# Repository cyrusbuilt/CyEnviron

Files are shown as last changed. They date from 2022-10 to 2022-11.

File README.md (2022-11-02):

# CyEnviron

Environmental Monitoring System (ESP-8266 based)



CyEnviron is an indoor environmental monitoring system designed to be integrated with home-automation systems. This repository contains the firmware, schematics, PCB design files, and OpenHAB3 integration.

## Theory of Operation

Once every 5 seconds (by default), CyEnviron will take the following measurements and then publish a status payload (in JSON format) to it's status topic in [MQTT](https://mqtt.org/):

- Temperature
- Humdity
- Barometric Pressure
- Altitude above sealevel
- Gas Resistance
- Ambient light level
- Indoor Air Quality (IAQ)
- Air Quality Index (AQI)
- CO2 Equivalent
- Breath Volatile Organic Compounds (Breath VOC)
- Dew Point

Ambient light level is sampled using an [LDR/CDS Photocell](https://www.electronics-notes.com/articles/electronic_components/resistors/light-dependent-resistor-ldr.php). All other measurements are sampled using an [Adafruit BME688/BME680](https://www.adafruit.com/product/5046). At present, the more advanced features such as integrated AI (BME688), IAQ (Indoor Air Quality), and VOC (Volatile Organic Compound) sampling are not yet supported (but will be in a future firmware release). Specifically, this project was designed to use the BME688 module, but the BME680 *can* be used instead (especially since the more advanced features of the 688 are not yet implemented).  In a future release, I also intend to support alarm thresholds for certain values. Once the threshold value(s) are exceeded an audible and visible alarm will trigger and also be published as part of the status payload.

## IMPORTANT NOTE

It is very important that you *DO NOT* touch the BME680/BME688 sensor during assembly so as not to contaminate the sensor. I'm not currently aware of any way to decontimnate it. Once contaminated, you will no longer get accurate readings.

## Project Structure

This is a [PlatformIO](https://platformio.org/) project, so please refer to the PlatformIO documentation for building,

```
|-- .github          # Continuous Integration stuff
|-- data             # Configuration data. Anything in here gets flashed when uploading a filesystem image.
|-- include          # Contains C++ header files for the firmware.
|-- openhab          # Contains OpenHAB3 integration files.
|-- schematics       # Contains schematics (EasyEDA and PDF), PCB design (EasyEDA and PDF), BOM, and gerbers.
|-- src              # Contains C++ source files for the firmware.
|-- LICENSE          # MIT open source license.
|-- platformio.ini   # PlatformIO project configuration file.
|-- README.md        # This file.
```

## Configuration

The config.h file contains default configuration directives. These options are the hardcoded default values that the system will initially boot with. However, if there is a config.json file present in the root of the SPIFFS file system, then its values will override the defaults. Here we'll discuss each option:

- DEBUG: Uncomment this define to generate additional debug output in the console.
- ENABLE_OTA: If you do not wish to support OTA updates, just comment this define.
- ENABLE_MDNS: If you do not wish to support [MDNS](https://tttapa.github.io/ESP8266/Chap08%20-%20mDNS.html), comment this define.
- CONFIG_FILE_PATH: This is the path to the configuration file. The default is /config.json. The values in this file will override these defaults.
- DEFAULT_SSID: Change this line to reflect the SSID of your WiFi network.
- DEFAULT_PASSWORD: Change this line to reflect the password to your WiFi network.
- CLOCK_TIMEZONE: The GMT offset for your timezone (EST [America/New York] is -4 when observing DST. It's -5 when not.)
- SERIAL_BAUD: While it is not recommended, you can change the BAUD rate of the serial port here.
- CHECK_WIFI_INTERVAL: The interval (in milliseconds) to check to make sure the device is still connected to WiFi, and if not attempt to reconnect. Default is 30 seconds.
- CHECK_SENSORS_INTERVAL: The interval (in millisceonds) to check the water depth.
- CLOCK_SYNC_INTERVAL: The interval (in milliseconds) to try to resync the clock with NTP. Default is 1 hour.
- DEVICE_NAME: This essentially serves as the host name of the device on the network (default is CYENVIRON).
- CHECK_MQTT_INTERVAL: The interval (in milliseconds) to check connectivity to the MQTT broker. If the connection is lost, a reconnect will occur. The default value is 35 seconds.
- MQTT_TOPIC_STATUS: The MQTT status topic to publish device status messages to. Default is 'cysump/status'.
- MQTT_TOPIC_CONTROL: The MQTT control topic to subscribe to for control messages. Default is 'cysump/control'.
- MQTT_BROKER: The hostname or IP of the MQTT broker.
- MQTT_PORT: The port on the MQTT broker to connect to. The default is 8883 (default port for MQTT over TLS).
- OTA_HOST_PORT: Defines the port to listen for OTA updates on. This option is ignored if ENABLE_OTA is disabled.
- OTA_PASSWORD: The password used to authenticate with the OTA server. This option is ignored if ENABLE_OTA is disabled.
- ip: The default IP address. By default, this devices boots with a static IP configuration. The default IP is 192.168.0.202. You can change that here if you wish.
- gw: The default gateway address. The current default is 192.168.0.1. You can change that here if you wish.
- sm: The subnet mask. By default, it is 255.255.255.0, but you can change that here if need be.

To override the default configuration options, you need to upload a filesystem image containing a file named 'config.json' in the root of the SPIFFS filesystem. The file should like something like this:

```json
{
    "hostname": "CLCONTROLLER",
    "useDHCP": false,
    "ip": "192.168.0.202",
    "gateway": "192.168.0.1",
    "subnetMask": "255.255.255.0",
    "dnsServer": "192.168.0.1",
    "wifiSSID": "your_ssid_here",
    "wifiPassword": "your_password_here",
    "otaPort": 8266,
    "otaPassword": "your_ota_password_here",
    "mqttBroker": "your_mqtt_broker_here",
    "mqttPort": 8883,
    "mqttControlChannel": "clcontroller/control",
    "mqttStatusChannel": "clcontroller/status",
    "mqttUsername": "your_mqtt_username",
    "mqttPassword": "your_mqtt_password",
	"timezone": -4
}
```

This configuration file is pretty self explanatory and one is included in the source. The file *MUST* be located in the "data" directory located in the root of the project in order to be picked up by the flash uploader (either via Serial or OTA). Each of the options in the configuration file are self-explanatory and match up with the hard-coded default settings mentioned above. If this file is not present when the firmware boots, a new file will be created and populated with the hardcoded defaults. These defaults can then be changed via the fail-safe menu and saved. You'll notice a couple of additional options in the config.json file not present in config.h. They are as follows:

- mqttUsername: If you have enabled password authentication on your MQTT broker, provide the username here.
- mqttPassword: If you have enabled password authentication on your MQTT broker, provide the password for the username above. If *both* the username and password are provided, then CLController will attempt to connect to the broker with the provided credentials; Otherwise, it will attempt to connect without credentials.
- mqttControlChannel: The MQTT control topic to subscribe to in order to receive device commands.
- mqttStatusChannel: The MQTT status topic to publish device status to.

## Getting Started

After you've configured everything the way you need it (as discussed above), build the firmware by either clicking "Build" in the PlatformIO tasks menu, or by opening a terminal to the project directory and typing:

```bash
> pio run
```

NOTE: The first time you flash the Huzzah, you need to do so over serial (since the OTA code isn't there yet), but subsequent uploads can be done via OTA if configured properly.

The next thing to do is connect the Huzzah to your computer using an FTDI cable like [this one](https://www.adafruit.com/product/70?gclid=EAIaIQobChMIm7-50ZiZ5AIVlIvICh284QPxEAQYBCABEgJkcPD_BwE) and then configure the port in platformio.ini like so:

```ini
[env:huzzah]
monitor_speed = 115200
monitor_port = /dev/cu.usbserial-AL05HSL2  ; Change this to match your port if necessary
```

With the above mentioned FTDI cable attached to my MacBook, the port appears as it does in the config file above (usually PlatformIO is pretty good about auto-detecting the port for you).

Now all you have to do is flash the firmware onto the Huzzah. You can do this by first pressing and holding the "GPIO" button and then press the "reset" button and let go of both on the Huzzah to put it into flash mode (this is not necessary when you flash via OTA), then click the "Upload and Monitor" task in the PlatformIO menu or by typing the following into the terminal:

```bash
> pio run --target upload --target monitor
```

Once complete, press the "reset" button on the Huzzah. You should see the device boot up in the serial console. Now put the device back into flash mode.  Configure the config.json file as needed and click the "Upload File System Image" task in the PlatformIO menu. When finished, press the "reset" button again and the device will reboot and come back up with your new configuration settings. Of course, to monitor the console, you can click the "Monitor" task from the PlatformIO menu or run the following command:

```bash
> pio run --target monitor
```

## OTA Updates

If you wish to be able to upload firmware updates Over-the-Air, then besides leaving the ENABLE_OTA option uncommented, you will also need to uncomment all the upload_* lines in platformio.ini, and change the line 'upload_port = ' line to reflect the IP of the device and the line '--auth=' to reflect whatever OTA_PASSWORD is set to. Then when you click "upload" from the PlatformIO tasks (or if you execute 'pio run --target upload' from the command line) it should upload directly over WiFi and once completed, the device will automatically flash itself and reboot with the new version. If you wish to upload a new configuration file, you can also do this via OTA. Assuming the above-mentioned settings are configured, you can then click "Upload File System Image" from the PlatformIO project tasks.

## Serial Console

If the device ever fails to connect to WiFi or if you press the 'I' key on your keyboard while in the serial console, normal operation of the device is suspended and the device will fall into a 'fail-safe' mode and present the user with a command menu, which can be use to re-configure the device, reboot, manually read sensor data, etc.

## Integration

As previously mentioned, this was intended to be integrated with 3rd-party systems (ie. Home Automation). While my personal preference is [OpenHAB](https://www.openhab.org/), since CyEnviron communicates over MQTT, it can be integrated with any other system that can use MQTT as well (ie. [Home Assistant](https://www.home-assistant.io/), [Node-RED](https://nodered.org/), etc). While the integration files included in this repo are for OpenHAB, you should be able to fairly easily create your own configuration files to integrate with other systems.

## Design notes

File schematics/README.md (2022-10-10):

# CyEnviron Schematics

All files were produced using [EasyEDA](https://easyeda.com/). The following is a list of files and what they are:

- BOM_PCB_CyEnviron.csv   - The Bill of Materials in CSV format.
- PCB_CyEnviron.json      - The original EasyEDA CAD file of the PCB.
- PCB_CyEnviron.pdf       - A PDF version of the PCB view.
- README.md               - This file.
- SCH_CyEnviron.json      - The original EasyEDA CAD file of the schematic.
- SCH_CyEnviron.pdf       - A PDF version of the schematic view.
- gerber                  - Contains the production gerber files for PCB fabrication.

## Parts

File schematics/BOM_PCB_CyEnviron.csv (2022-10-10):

ID | Name | Designator | Footprint | Quantity | Manufacturer Part | Manufacturer | Supplier | Supplier Part | Price
1 | LED 5MM YELLOW | D3 | LED 5MM YELLOW | 1
2 | BUZZERPTH | SG1 | BUZZER-12MM | 1
3 | 100nF | C1 | 100NF | 1 | CT4-0805Y104M500 | ReliaPro | LCSC | C46756
4 | LED 5MM GREEN | D1 | LED 5MM GREEN | 1
5 | 5mm | D2 | PKG-LED-5MM-RED | 1 | L-1503EC | KINGBRIGHT | Element14 | 1003201
6 | HEADER 1X6 | H1 | HEADER-1X6-2.54MM | 1
7 | M023.5MM | JP2 | SCREWTERMINAL-3.5MM-2 | 1
8 | 150 | R2 | PKG-0.25W RESISTOR | 1 | MCF 0.25W 150R | MULTICOMP | Element14 | 9339175
9 | Toggle_Switch | SW1 | SPDT_TOGGLE_SWITCH | 1 |  |  | RS-Online | 734-7220
10 | ADAFRUIT HUZZAH ESP8266 BREAKOUT COPY | U1 | HUZZAH 8266 | 1 |  | Adafruit
11 | Adafruit BME688 Breakout | U2 | ADAFRUIT BME688 BREAKOUT | 1
12 | Photoresistor-5528 | U3 | SNR2-3.0 | 1 | Photoresistor-5528 |  | SeeedStudio | 314020017
13 | 0.1UF/250V | C2 | CAP-TH_L8.8-W3.6-P7.30-D0.5 | 1 | 0.1uF/250V | null | LCSC | C9900015263

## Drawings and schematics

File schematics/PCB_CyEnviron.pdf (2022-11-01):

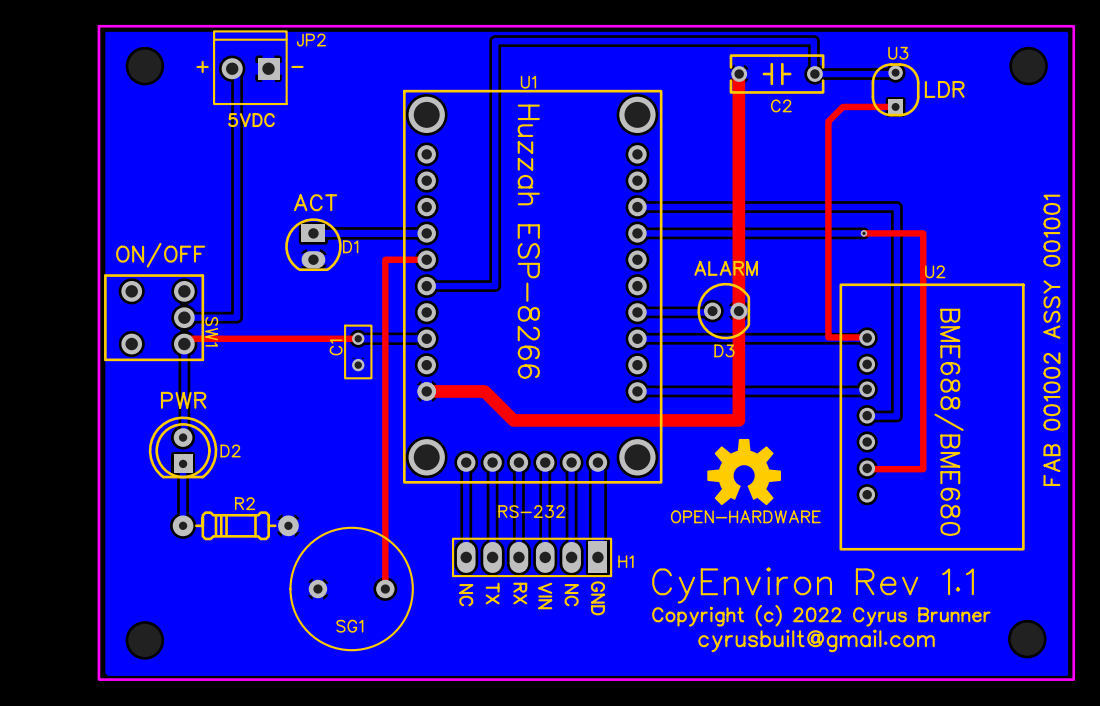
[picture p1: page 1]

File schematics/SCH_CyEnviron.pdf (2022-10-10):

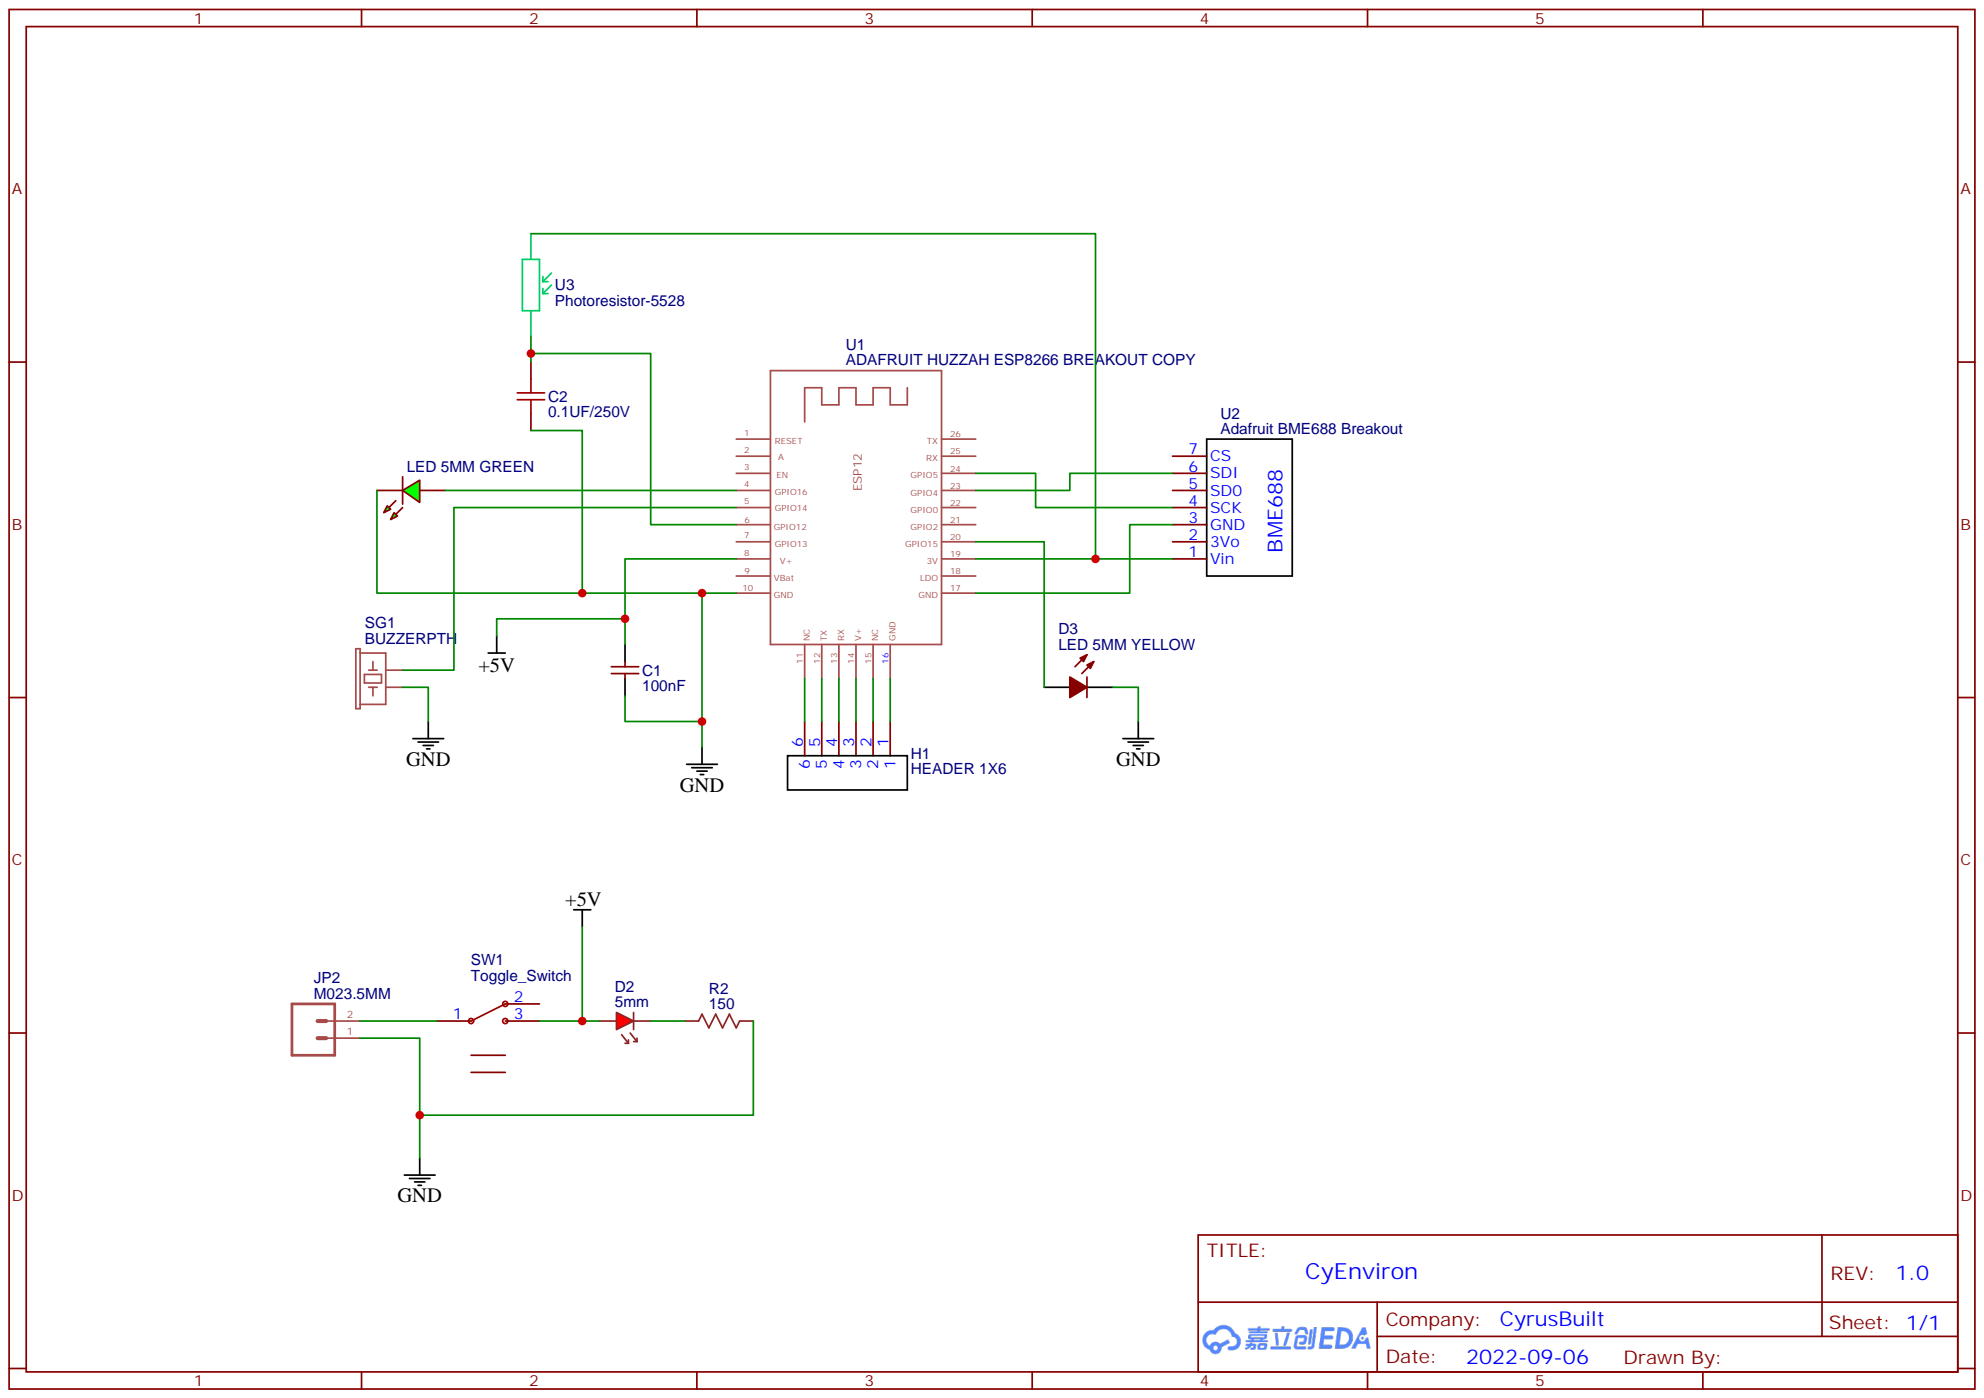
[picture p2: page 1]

ADAFRUIT HUZZAH ESP8266 BREAKOUT COPY

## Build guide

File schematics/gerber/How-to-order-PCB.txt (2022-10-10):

How to Order PCB

Please refer to:
https://docs.easyeda.com/en/PCB/Order-PCB

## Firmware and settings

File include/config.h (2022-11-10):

#ifndef _CONFIG_H
#define _CONFIG_H

#include <IPAddress.h>

#define DEBUG                                       // Comment to disable debug output.
#define DEVICE_NAME "CYENVIRON"		                // The device name (hostname).
#define DEVICE_CLASS "cyenviron"                    // The device class (used for discovery).
#define BAUD_RATE 115200                            // The BAUD rate (speed) of the serial port (console).
#define ENABLE_OTA                                  // Comment to disable OTA (over-the-air) firmware updates.
#define ENABLE_MDNS                                 // Comment to disable MDNS (multicast-DNS) support.
#define CONFIG_FILE_PATH "/config.json"             // Config file path. Do not alter unless you are sure.
#define DEFAULT_SSID "your_ssid_here"               // Put the SSID of your WiFi here.
#define DEFAULT_PASSWORD "your_wifi_password"       // Put your WiFi password here.
#define CLOCK_TIMEZONE -4                           // The timezone this device is located in. (For example, EST when observing DST = GMT -4, when not = GMT -5).
#define CHECK_WIFI_INTERVAL 30000                   // How often to check WiFi status (millis)
#define CLOCK_SYNC_INTERVAL 3600000                 // How often to sync the local clock with NTP (millis)
#define CHECK_SENSORS_INTERVAL 5000                 // How often to chec the sensors.
#define CHECK_MQTT_INTERVAL 60000 * 5               // MQTT connectivity check interval (millis).
#define MQTT_TOPIC_STATUS "cyenviron/status"     	// MQTT status topic to publish to.
#define MQTT_TOPIC_CONTROL "cyenviron/control"   	// MQTT control topic to subscribe to.
#define MQTT_TOPIC_DISCOVERY "redqueen/config"      // MQTT discovery topic to publish to.
#define MQTT_BROKER "your_mqtt_broker_ip"           // MQTT broker hostname or IP.
#define MQTT_PORT 8883                              // MQTT port number.
#ifdef ENABLE_OTA
    #include <ArduinoOTA.h>
    #define OTA_HOST_PORT 8266                      // The OTA updater port.
    #define OTA_PASSWORD "your_ota_password_here"   // The OTA updater password.
#endif
const IPAddress defaultIp(192, 168, 0, 216);                     // Default static IP address.
const IPAddress defaultGw(192, 168, 0, 1);                       // Default static gateway address.
const IPAddress defaultSm(255, 255, 255, 0);                     // Default static subnet mask.
const IPAddress defaultDns(192, 168, 0, 1);                      // Default static primary DNS address.

typedef struct {
    // Network stuff
    String hostname;
    String ssid;
    String password;
    IPAddress ip;
    IPAddress gw;
    IPAddress sm;
    IPAddress dns;
    bool useDhcp;

    uint8_t clockTimezone;

    // MQTT stuff
    String mqttTopicStatus;
    String mqttTopicControl;
    String mqttTopicDiscovery;
    String mqttBroker;
    String mqttUsername;
    String mqttPassword;
    uint16_t mqttPort;

    // OTA stuff
    uint16_t otaPort;
    String otaPassword;
} config_t;

#endif

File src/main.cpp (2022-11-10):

/**
 * @file main.cpp
 * @author Cyrus Brunner (cyrusbuilt at gmail dot com)
 * @brief Firmware for the CyEnviron ESP8266-based Evironmental sensor module.
 * This module samples temperature, humidity, barometric pressure, gas
 * resistance and ambient light level. It also derives altitude above
 * sea-level and eventually will provide measurements for IAQ (Indoor Air
 * Quality) and VOC (Volatile Organic Compounds) which can be used to detect
 * the presence of dangerous gasses such as Carbon Monoxide, etc.
 * @version 1.4
 * @date 2022-09-19
 * 
 * @copyright Copyright (c) 2022 Cyrus Brunner
 * 
 */

#ifndef ESP8266
    #error This firmware is only compatible with ESP8266 controllers.
#endif

#include <Arduino.h>
#include <FS.h>
#include <time.h>
#include <TZ.h>
#include <Wire.h>
#include "config.h"
#include "ArduinoJson.h"
#include "ESPCrashMonitor.h"
#include "Console.h"
#include "Buzzer.h"
#include "LED.h"
#include "PubSubClient.h"
#include "ResetManager.h"
#include "TaskScheduler.h"
#include "TelemetryHelper.h"
#include "bsec.h"
#include "Environment.h"
#include "LDR.h"

#define FIRMWARE_VERSION "1.4"

// Pin definitions
#define PIN_WIFI_LED 16
#define PIN_LDR 12
#define PIN_ALARM_LED 15
#define PIN_ALARM_BUZZER 14

// Forward declarations
void onCheckWifi();
void onCheckMqtt();
void onSyncClock();
void onReadSensors();
void onMqttMessage(char* topic, byte* payload, unsigned int length);

// Global vars.
#ifdef ENABLE_MDNS
    #include <ESP8266mDNS.h>
    MDNSResponder mdns;
#endif
WiFiClient wifiClient;
PubSubClient mqttClient(wifiClient);
Task tCheckWiFi(CHECK_WIFI_INTERVAL, TASK_FOREVER, &onCheckWifi);
Task tCheckMqtt(CHECK_MQTT_INTERVAL, TASK_FOREVER, &onCheckMqtt);
Task tClockSync(CLOCK_SYNC_INTERVAL, TASK_FOREVER, &onSyncClock);
Task tReadSensors(CHECK_SENSORS_INTERVAL, TASK_FOREVER, &onReadSensors);
Scheduler taskMan;
LED wifiLED(PIN_WIFI_LED, NULL);
LED alarmLED(PIN_ALARM_LED, NULL);
Buzzer alarmBuzzer(PIN_ALARM_BUZZER, NULL, "alarm");
Bsec iaqSensor;
LDR ldr(PIN_LDR);
config_t config;
env_t envData;
bool filesystemMounted = false;
volatile SystemState sysState = SystemState::BOOTING;

/**
 * @brief Get the current date/time as string (adjusted for local time and DST).
 * 
 * @return String The current time string.
 */
String getTimeInfo() {
    time_t now = time(nullptr);
    struct tm *timeinfo = localtime(&now);
    String result = String(asctime(timeinfo));
    result.replace("\n", "");
    return result;
}

/**
 * @brief Synchronize the local system clock via NTP. Note: This does not take DST
 * into account. Currently, you will have to adjust the CLOCK_TIMEZONE define
 * manually to account for DST when needed.
 */
void onSyncClock() {
    wifiLED.on();
    configTzTime(TZ_America_New_York, "pool.ntp.org");

    Serial.print("INIT: Waiting for NTP time sync...");
    delay(500);
    while (!time(nullptr)) {
        wifiLED.off();
        ESPCrashMonitor.iAmAlive();
        Serial.print(F("."));
        delay(500);
        wifiLED.on();
    }
    
    wifiLED.off();
    Serial.println(F(" DONE"));
    Serial.print(F("INFO: Current time: "));
    Serial.println(getTimeInfo());
}

/**
 * @brief Publishes the current system status as a JSON payload to the MQTT
 * status topic, if connected. This will also flash the WiFi activity LED.
 */
void publishSystemState() {
    if (mqttClient.connected()) {
        wifiLED.on();

        // TODO Make reported measurements configurable (imperial vs metric, or both).
        DynamicJsonDocument doc(400);
        doc["clientId"] = config.hostname.c_str();
        doc["firmwareVersion"] = FIRMWARE_VERSION;
        doc["systemState"] = (uint8_t)sysState;
        doc["altitudeFeet"] = envData.altitudeF;
        doc["gasKohms"] = envData.gasKohms;
        doc["humidity"] = envData.humidity;
        doc["pressureHpa"] = envData.pressureHpa;
        doc["tempF"] = envData.tempF;
        doc["brightness"] = envData.brightness;
        doc["lightLevel"] = (uint8_t)envData.lightLevel;
        doc["alarm"] = envData.alarmCondition;
        doc["iaq"] = envData.iaq;
        doc["co2Equivalent"] = envData.co2Equivalent;
        doc["breathVoc"] = envData.breathVoc;
        doc["dewPoint"] = envData.dewPointF;
        doc["aqi"] = (uint8_t)envData.aqi;
        doc["lastUpdate"] = envData.lastUpdate;

        String jsonStr;
        size_t len = serializeJson(doc, jsonStr);
        Serial.print(F("INFO: Publishing system state: "));
        Serial.println(jsonStr);
        if (!mqttClient.publish(config.mqttTopicStatus.c_str(), jsonStr.c_str(), len)) {
            Serial.println(F("ERROR: Failed to publish message."));
        }

        doc.clear();
        wifiLED.off();
    }
}

/**
 * @brief Publishes a device disovery packet to the configured discovery topic.
 */
void publishDiscoveryPacket() {
    if (mqttClient.connected()) {
        wifiLED.on();

        DynamicJsonDocument doc(250);
        doc["name"] = config.hostname;
        doc["class"] = DEVICE_CLASS;
        doc["statusTopic"] = config.mqttTopicStatus;
        doc["controlTopic"] = config.mqttTopicControl;

        String jsonStr;
        size_t len = serializeJson(doc, jsonStr);
        Serial.print(F("INFO: Publishing discovery packet: "));
        Serial.println(jsonStr);
        if (!mqttClient.publish(config.mqttTopicDiscovery.c_str(), jsonStr.c_str(), len)) {
            Serial.println(F("ERROR: Failed to publish message."));
        }

        doc.clear();
        wifiLED.off();
    }
}

/**
 * @brief Triggers an alarm condition. This will set the system state, turn the
 * alarm LED and buzzer on, and then publish the system state.
 * 
 * @param reason The reason for the alarm.
 */
void raiseAlarm(const char* reason) {
    Serial.print(F("ALARM: !!! "));
    Serial.print(reason);
    Serial.println(F(" !!!"));
    alarmLED.on();
    alarmBuzzer.on();
    sysState = SystemState::ALARM;
    envData.alarmCondition = strdup(reason);
    publishSystemState();
}

/**
 * @brief Clears the alarm state, turns the alarm LED and buzzer off, then
 * publishes the status update.
 */
void clearAlarm() {
    Serial.println(F("INFO: Alarm condition cleared."));
    alarmBuzzer.off();
    alarmLED.off();
    sysState = SystemState::NORMAL;
    envData.alarmCondition = "";
    publishSystemState();
}

/**
 * @brief Silences the audible alarm, but does not clear the alarm state.
 */
void silenceAlarm() {
    if (sysState == SystemState::ALARM) {
        Serial.println(F("WARN: Alarm silenced."));
        alarmBuzzer.off();
    }
}

/**
 * @brief Checks for alarm conditions. This will clear an active alarm if the
 * alarm conditions drop below threshold or raise an alarm if conditions go
 * above threshold. Trigger an alarm causes a number of things to happen:
 * 1) Alarm buzzer turns on.
 * 2) Alarm LED turns on.
 * 3) System state changes to ALARM.
 * 4) alarmCondition in env data set to reason for alarm.
 * 5) Updated state is then published to MQTT status topic.
 */
void checkAlarm() {
    switch (envData.aqi) {
        case AQI::EXCELLENT:
        case AQI::GOOD:
        case AQI::LIGHTLY_POLLUTED:
            if (sysState == SystemState::ALARM) {
                clearAlarm();
            }
            break;
        case AQI::MODERATELY_POLLUTED:
        case AQI::HEAVILY_POLLUTED:
        case AQI::SEVERELY_POLLUTED:
        case AQI::EXTREME_POLLUTION:
            if (sysState != SystemState::ALARM) {
                raiseAlarm("High pollution level!");
            }
            break;
        default:
            break;
    }

    // TODO CO2 levels factor in to the IAQ/AQI level, but do we want a separate check for that?
    // NOTE acceptable CO2 range is 400 - 650.

    // TODO should we have an alarm for temperature/humidity?
}

/**
 * @brief Checks that status of the BME680/688 sensor and reports any errors
 * or warnings detected.
 */
void checkIaqSensorStatus() {
    String output = "";
    if (iaqSensor.stabStatus != BSEC_OK) {
        if (iaqSensor.stabStatus < BSEC_OK) {
            output = "ERROR: BSEC error code: ";
        }
        else {
            output = "WARN: BSEC warn code: ";
        }

        output += String(iaqSensor.status);
        Serial.println(output);
    }

    if (iaqSensor.bme680Status != BME680_OK) {
        if (iaqSensor.bme680Status < BME680_OK) {
            output = "ERROR: BME680/688 error code: ";
        }
        else {
            output = "WARN: BME680/688 warn code: ";
        }

        output += String(iaqSensor.bme680Status);
        Serial.println(output);
    }
}

/**
 * @brief Read all the sensor data and publishes the updated state data.
 */
void onReadSensors() {
    Serial.println(F("INFO: Reading sensor data ..."));
    if (!iaqSensor.run()) {
       checkIaqSensorStatus();
       return;
    }

    ldr.performReading();

    envData.altitudeM = EnvUtils::getAltitude(iaqSensor.pressure, AVG_PRESSURE_SEALEVEL_HPA);
    envData.altitudeF = envData.altitudeM * 3.281;
    envData.gasKohms = iaqSensor.gasResistance / 10000;
    envData.humidity = iaqSensor.humidity;
    envData.pressureHpa = iaqSensor.pressure / 100.0;
    envData.tempC = iaqSensor.temperature;
    envData.tempF = EnvUtils::convertTempCtoF(envData.tempC);
    envData.iaq = iaqSensor.staticIaq;
    envData.co2Equivalent = iaqSensor.co2Equivalent;
    envData.breathVoc = iaqSensor.breathVocEquivalent;
    envData.dewPointC = EnvUtils::getDewPoint(envData.tempC, envData.humidity);
    envData.dewPointF = EnvUtils::convertTempCtoF(envData.dewPointC);
    envData.aqi = EnvUtils::getAQI(envData.iaq);
    envData.brightness = ldr.readSensorBrightness();
    envData.lightLevel = ldr.getBrightnessLevel();
    envData.lastUpdate = getTimeInfo();

    checkAlarm();
    publishSystemState();
}

/**
 * @brief Resume normal operation. This will resume any suspended tasks.
 */
void resumeNormal() {
    Serial.println(F("INFO: Resuming normal operation..."));
    taskMan.enableAll();
    wifiLED.off();
    sysState = SystemState::NORMAL;
    publishSystemState();
}

/**
 * @brief Prints network information details to the serial console.
 */
void printNetworkInfo() {
    Serial.print(F("INFO: Local IP: "));
    Serial.println(WiFi.localIP());
    Serial.print(F("INFO: Gateway: "));
    Serial.println(WiFi.gatewayIP());
    Serial.print(F("INFO: Subnet mask: "));
    Serial.println(WiFi.subnetMask());
    Serial.print(F("INFO: DNS server: "));
    Serial.println(WiFi.dnsIP());
    Serial.print(F("INFO: MAC address: "));
    Serial.println(WiFi.macAddress());
    #ifdef DEBUG
        WiFi.printDiag(Serial);
    #endif
}

/**
 * @brief Perform a soft-reboot of the firmware.
 */
void reboot() {
    Serial.println(F("INFO: Rebooting..."));
    Serial.flush();
    delay(1000);
    ResetManager.softReset();
}

/**
 * @brief Saves configuration data to the config file.
 */
void saveConfiguration() {
    Serial.print(F("INFO: Saving configuration to "));
    Serial.print(CONFIG_FILE_PATH);
    Serial.println(F(" ... "));
    if (!filesystemMounted) {
        Serial.println(F("FAIL"));
        Serial.println(F("ERROR: Filesystem not mount."));
        return;
    }

    StaticJsonDocument<350> doc;
    doc["hostname"] = config.hostname;
    doc["useDhcp"] = config.useDhcp;
    doc["ip"] = config.ip.toString();
    doc["gateway"] = config.gw.toString();
    doc["subnetmask"] = config.sm.toString();
    doc["dnsServer"] = config.dns.toString();
    doc["wifiSSID"] = config.ssid;
    doc["wifiPassword"] = config.password;
    doc["timezone"] = config.clockTimezone;
    doc["mqttBroker"] = config.mqttBroker;
    doc["mqttPort"] = config.mqttPort;
    doc["mqttControlTopic"] = config.mqttTopicControl;
    doc["mqttStatusTopic"] = config.mqttTopicStatus;
    doc["mqttDiscoveryTopic"] = config.mqttTopicDiscovery;
    doc["mqttUsername"] = config.mqttUsername;
    doc["mqttPassword"] = config.mqttPassword;
    #ifdef ENABLE_OTA
        doc["otaPort"] = config.otaPort;
        doc["otaPassword"] = config.otaPassword;
    #endif

    File configFile = SPIFFS.open(CONFIG_FILE_PATH, "w");
    if (!configFile) {
        Serial.println(F("FAIL"));
        Serial.println(F("ERROR: Failed to open config file for writing."));
        doc.clear();
        return;
    }

    serializeJsonPretty(doc, configFile);
    doc.clear();
    configFile.flush();
    configFile.close();
    Serial.println(F("DONE"));
}

/**
 * @brief Helper method for printing warnings about configuration settings.
 * 
 * @param message The warning message to print.
 */
void printWarningAndContinue(const __FlashStringHelper *message) {
    Serial.println();
    Serial.println(message);
    Serial.print(F("INFO: Continuing... "));
}

/**
 * @brief Sets all the configuration values to their defaults.
 */
void setConfigurationDefaults() {
    String chipId = String(ESP.getChipId(), HEX);
    String defHostname = String(DEVICE_NAME) + "_" + chipId;

    config.hostname = defHostname;
    config.ip = defaultIp;
    config.mqttBroker = MQTT_BROKER;
    config.mqttPassword = "";
    config.mqttPort = MQTT_PORT;
    config.mqttTopicControl = MQTT_TOPIC_CONTROL;
    config.mqttTopicStatus = MQTT_TOPIC_STATUS;
    config.mqttTopicDiscovery = MQTT_TOPIC_DISCOVERY;
    config.mqttUsername = "";
    config.password = DEFAULT_PASSWORD;
    config.sm = defaultSm;
    config.ssid = DEFAULT_SSID;
    config.useDhcp = false;
    config.clockTimezone = CLOCK_TIMEZONE;
    config.dns = defaultDns;
    config.gw = defaultGw;

    #ifdef ENABLE_OTA
        config.otaPassword = OTA_PASSWORD;
        config.otaPort = OTA_HOST_PORT;
    #endif
}

/**
 * @brief Loads the configuration parameters into memory, defaulting the
 * configuration values where necessary.
 */
void loadConfiguration() {
    memset(&config, 0, sizeof(config));

    Serial.print(F("INFO: Loading config file "));
    Serial.print(CONFIG_FILE_PATH);
    Serial.print(F(" ... "));
    if (!filesystemMounted) {
        Serial.println(F("FAIL"));
        Serial.println(F("ERROR: Filesystem not mounted."));
        return;
    }

    if (!SPIFFS.exists(CONFIG_FILE_PATH)) {
        Serial.println(F("FAIL"));
        Serial.println(F("WARN: Config file does not exist. Creating with default config ..."));
        saveConfiguration();
        return;
    }

    File configFile = SPIFFS.open(CONFIG_FILE_PATH, "r");
    if (!configFile) {
        Serial.println(F("FAIL"));
        Serial.println(F("ERROR: Unable to open config file. Using default config."));
        return;
    }

    size_t size = configFile.size();
    uint16_t freeMem = ESP.getMaxFreeBlockSize() - 512;
    if (size > freeMem) {
        Serial.println(F("FAIL"));
        Serial.print(F("ERROR: Not enough free memory to load document. Size = "));
        Serial.print(size);
        Serial.print(F(", Free = "));
        Serial.println(freeMem);
        configFile.close();
        return;
    }

    DynamicJsonDocument doc(freeMem);
    DeserializationError error = deserializeJson(doc, configFile);
    if (error) {
        Serial.println(F("FAIL"));
        Serial.println(F("ERROR: Fail to parse config file to JSON. Using default config."));
        configFile.close();
        return;
    }

    doc.shrinkToFit();
    configFile.close();

    String chipId = String(ESP.getChipId(), HEX);
    String defHostname = String(DEVICE_NAME) + "_" + chipId;

    config.hostname = doc.containsKey("hostname") ? doc["hostname"].as<String>() : defHostname;
    config.useDhcp = doc.containsKey("isDhcp") ? doc["isDhcp"].as<bool>() : false;
    
    if (doc.containsKey("ip")) {
        if (!config.ip.fromString(doc["ip"].as<String>())) {
            printWarningAndContinue(F("WARN: Invalid IP in configuration. Falling back to factory default."));
        }
    }
    else {
        config.ip = defaultIp;
    }

    if (doc.containsKey("gateway")) {
        if (!config.gw.fromString(doc["gateway"].as<String>())) {
            printWarningAndContinue(F("WARN: Invalid gateway in configuration. Falling back to factory default."));
        }
    }
    else {
        config.gw = defaultGw;
    }

    if (doc.containsKey("subnetmask")) {
        if (!config.sm.fromString(doc["subnetmask"].as<String>())) {
            printWarningAndContinue(F("WARN: Invalid subnet mask in configuration. Falling back to factory default."));
        }
    }
    else {
        config.sm = defaultSm;
    }

    if (doc.containsKey("dns")) {
        if (!config.dns.fromString(doc["dns"].as<String>())) {
            printWarningAndContinue(F("WARN: Invalid DNS IP in configuration. Falling back to factory default."));
        }
    }
    else {
        config.dns = defaultDns;
    }

    config.ssid = doc.containsKey("wifiSSID") ? doc["wifiSSID"].as<String>() : DEFAULT_SSID;
    config.password = doc.containsKey("wifiPassword") ? doc["wifiPassword"].as<String>() : DEFAULT_PASSWORD;
    config.clockTimezone = doc.containsKey("timezone") ? doc["timezone"].as<uint8_t>() : CLOCK_TIMEZONE;
    config.mqttBroker = doc.containsKey("mqttBroker") ? doc["mqttBroker"].as<String>() : MQTT_BROKER;
    config.mqttPort = doc.containsKey("mqttPort") ? doc["mqttPort"].as<int>() : MQTT_PORT;
    config.mqttTopicControl = doc.containsKey("mqttControlTopic") ? doc["mqttControlTopic"].as<String>() : MQTT_TOPIC_CONTROL;
    config.mqttTopicStatus = doc.containsKey("mqttStatusTopic") ? doc["mqttStatusTopic"].as<String>() : MQTT_TOPIC_STATUS;
    config.mqttTopicDiscovery = doc.containsKey("mqttDiscoveryTopic") ? doc["mqttDiscoveryTopic"].as<String>() : MQTT_TOPIC_DISCOVERY;
    config.mqttUsername = doc.containsKey("mqttUsername") ? doc["mqttUsername"].as<String>() : "";
    config.mqttPassword = doc.containsKey("mqttPassword") ? doc["mqttPassword"].as<String>() : "";

    #ifdef ENABLE_OTA
        config.otaPort = doc.containsKey("otaPort") ? doc["otaPort"].as<uint16_t>() : MQTT_PORT;
        config.otaPassword = doc.containsKey("otaPassword") ? doc["otaPassword"].as<String>() : OTA_PASSWORD;
    #endif

    doc.clear();
    Serial.println(F("DONE"));
}

/**
 * @brief Perform a "factory restore" of the configration data. This clears
 * configuration data on flash and reboots after a 5 second countdown. This
 * will force a configuration file to be generated on restart using default
 * values.
 */
void doFactoryRestore() {
    Serial.println();
    Serial.println(F("Are you sure you wish to restore to factory default? (Y/n)"));
    Console.waitForUserInput();
    
    String str = Console.getInputString();
    if (str == "Y" || str == "y") {
        Serial.print(F("INFO: Clearing current config... "));
        if (filesystemMounted) {
            if (SPIFFS.remove(CONFIG_FILE_PATH)) {
                Serial.println(F("DONE"));
                Serial.print(F("INFO: Removed file: "));
                Serial.println(CONFIG_FILE_PATH);

                Serial.print(F("INFO: Rebooting in "));
                for (uint8_t i = 5; i >= 1; i--) {
                    Serial.print(i);
                    Serial.print(F(" "));
                    delay(1000);
                }

                reboot();
            }
            else {
                Serial.println(F("FAIL"));
                Serial.println(F("ERROR: Failed to delete cofiguration file."));
            }
        }
        else {
            Serial.println(F("FAIL"));
            Serial.println(F("ERROR: Filesystem not mounted."));
        }
    }

    Serial.println();
}

/**
 * @brief Scan for available networks and dump each discovered network to the console.
 */
void getAvailableNetworks() {
    ESPCrashMonitor.defer();
    Serial.println(F("INFO: Scanning WiFi networks..."));
    int numNetworks = WiFi.scanNetworks();
    for (int i = 0; i < numNetworks; i++) {
        Serial.print(F("ID: "));
        Serial.print(i);
        Serial.print(F("\tNetwork name: "));
        Serial.print(WiFi.SSID(i));
        Serial.print(F("\tSignal strength:"));
        Serial.println(WiFi.RSSI(i));
    }
    Serial.println(F("----------------------------------"));
}

/**
 * @brief Reconnect to the MQTT broker and resubscribe to the control topic
 * if no longer connected.
 * 
 * @return true If already connected or successfully reconnected.
 * @return false If no longer connected and unable reconnect.
 */
bool reconnectMqttClient() {
    if (!mqttClient.connected()) {
        wifiLED.on();
        Serial.print(F("INFO: Attempting to establish MQTT connection to "));
        Serial.print(config.mqttBroker);
        Serial.print(F(" on port "));
        Serial.print(config.mqttPort);
        Serial.println(F(" ... "));

        bool didConnect = false;
        if (config.mqttUsername.length() > 0 && config.mqttPassword.length() > 0) {
            didConnect = mqttClient.connect(config.hostname.c_str(), config.mqttUsername.c_str(), config.mqttPassword.c_str());
        }
        else {
            didConnect = mqttClient.connect(config.hostname.c_str());
        }

        if (didConnect) {
            Serial.print(F("INFO: Subscribing to topic: "));
            Serial.println(config.mqttTopicControl);
            mqttClient.subscribe(config.mqttTopicControl.c_str());

            Serial.print(F("INFO: Publishing to topic: "));
            Serial.println(config.mqttTopicStatus);

            Serial.print(F("INFO: Discovery topic: "));
            Serial.println(config.mqttTopicDiscovery);
        }
        else {
            String failReason = TelemetryHelper::getMqttStateDesc(mqttClient.state());
            Serial.print(F("ERROR: Failed to connect to MQTT broker: "));
            Serial.println(failReason);
            return false;
        }

        wifiLED.off();
    }

    return true;
}
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
void loop() {
    ESPCrashMonitor.iAmAlive();
    Console.checkInterrupt();
    taskMan.execute();
    #ifdef ENABLE_MDNS
        mdns.update();
    #endif
    #ifdef ENABLE_OTA
        ArduinoOTA.handle();
    #endif
    mqttClient.loop();
}

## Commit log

2022-11-01 Add ground copper fill
    [Drill_NPTH_Through.DRL, Drill_PTH_Through.DRL, Gerber_BoardOutlineLayer.GKO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]
2022-11-02 Adding AQI, IAQ, CO2, and dew pt. Switch to BSEC.
